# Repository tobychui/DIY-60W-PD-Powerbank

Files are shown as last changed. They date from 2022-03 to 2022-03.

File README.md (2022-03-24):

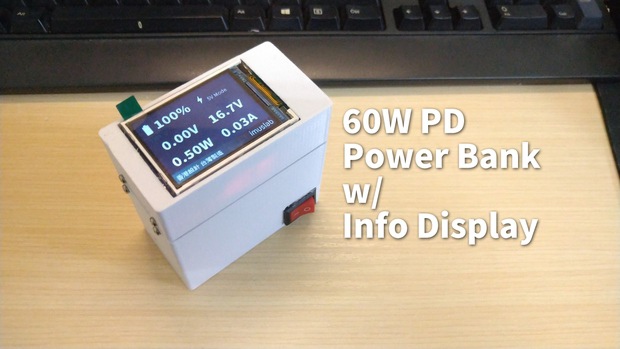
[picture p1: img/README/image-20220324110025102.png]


# DIY-60W-PD-Powerbank

A DIY 60W PD Power bank with real-time battery display for charging your laptop and smartphone

## Introduction

This is a type C only, 20V 3A (60W) supported power bank built by myself. The whole build process is about 2 months and it is a really handy little device to charge your laptop on the go. I designed this so that I don't need to always find a seat with socket nearby during lecture and it really helped me a lot during long and boring lectures :)

## Specification

- Panasonic 14.8V 3200mAh 4S 18650 battery pack
- PD3.0  5 / 9 / 15 / 20V output (Max 20V 3A, 60W)
- Real-time HMI display for battery information (Output power, voltage, battery voltage and drawing current)
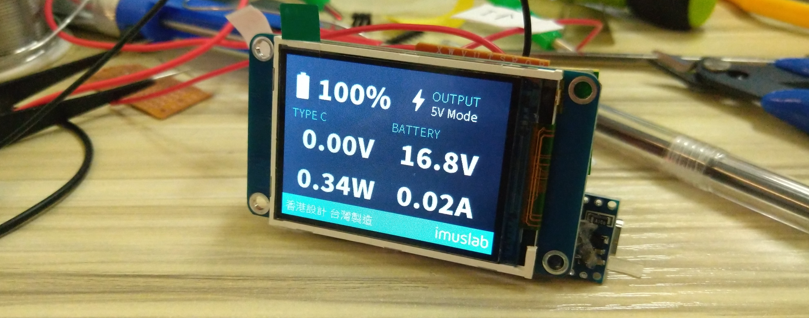
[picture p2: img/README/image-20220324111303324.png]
  

## Building Instructions

This power bank contain 3 main parts. The power bank circuits (the battery, PD management board etc), the Arduino batinfo reader (Arduino, voltage dividers and current sensors) and the HMI display. The overall circuit diagram can be simplified as below.

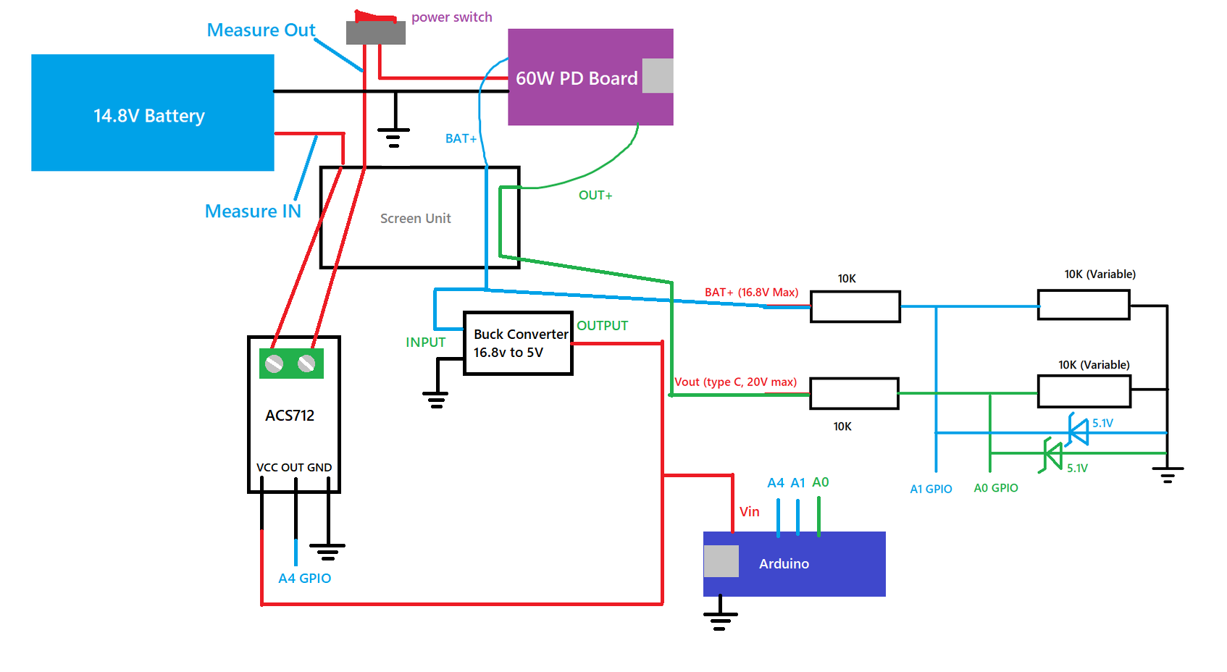
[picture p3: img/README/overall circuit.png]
overall circuit


All the parts then can be glued at the back of the HMI display as follows.

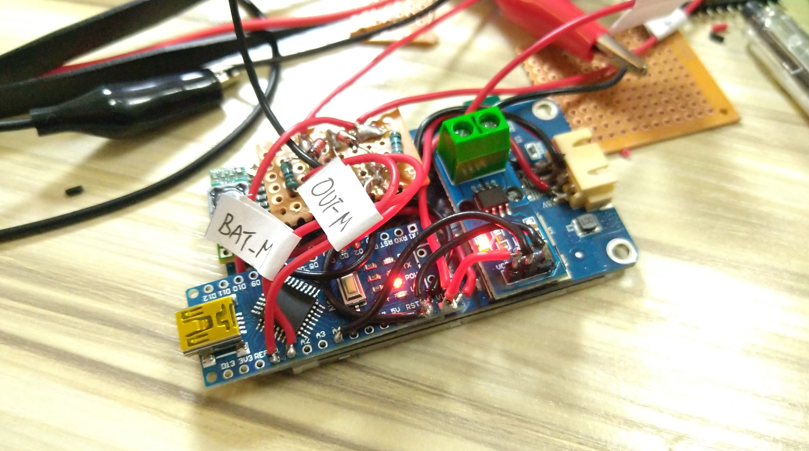
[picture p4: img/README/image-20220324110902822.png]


For more details on the build instructions, see the "Tutorial" folder.

For calibration process for the Arduino measurement sensors, see the Arduino Code folder's README file.

## Case

The case can be printed with a normal FDM printer. See "Case "folder for more information.

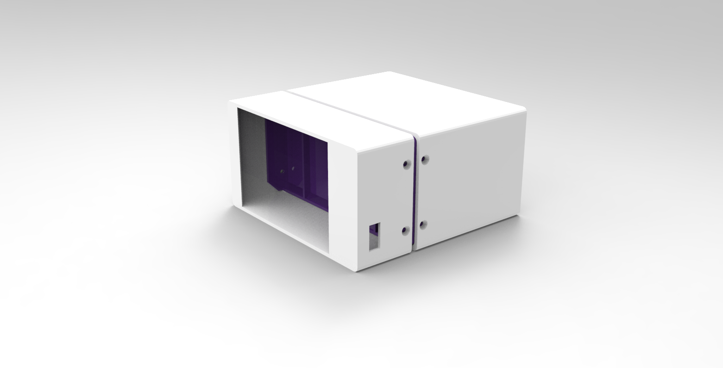
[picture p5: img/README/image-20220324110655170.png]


## Final Product

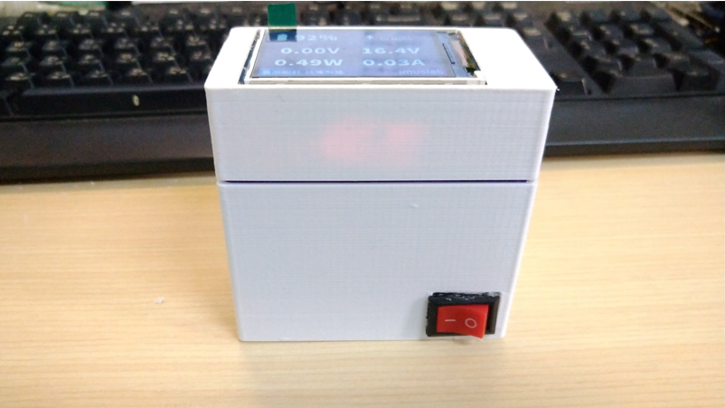
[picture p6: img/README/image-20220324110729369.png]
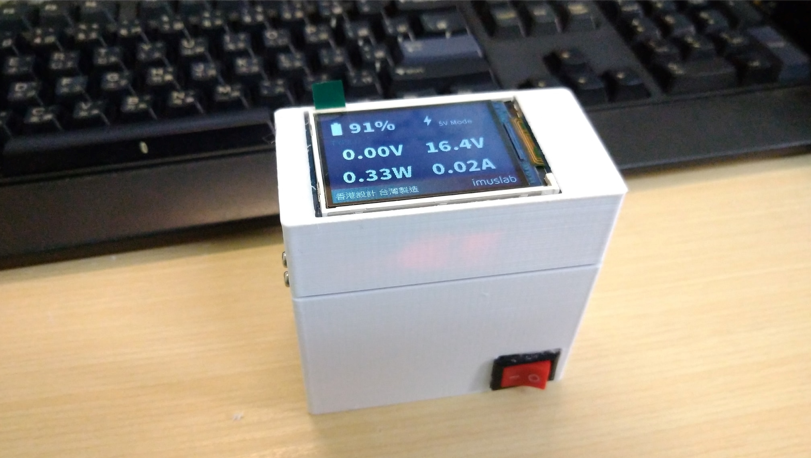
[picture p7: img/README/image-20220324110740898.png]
|  |  |
| --- | --- |
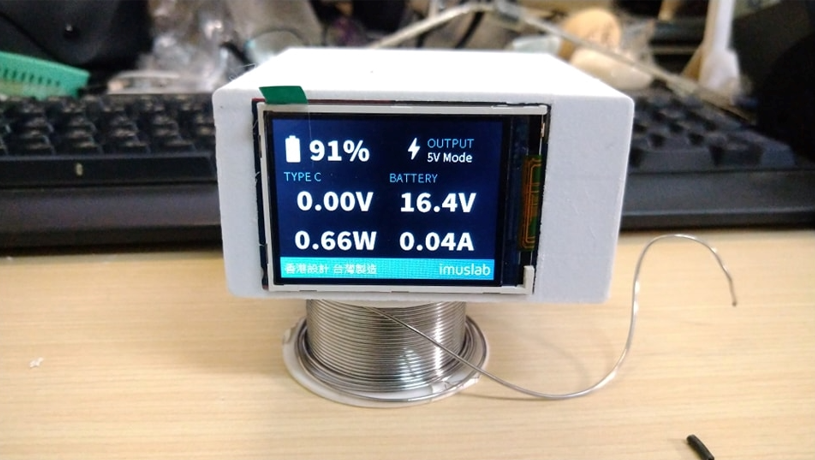
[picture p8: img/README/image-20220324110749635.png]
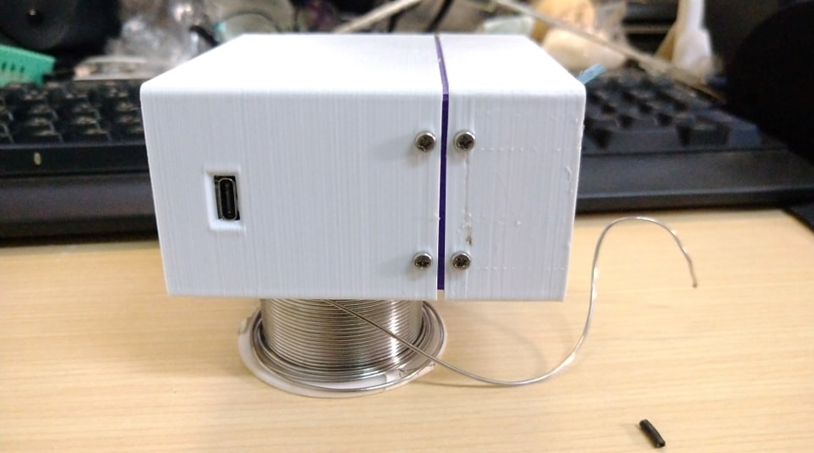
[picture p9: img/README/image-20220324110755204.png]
|  |  |
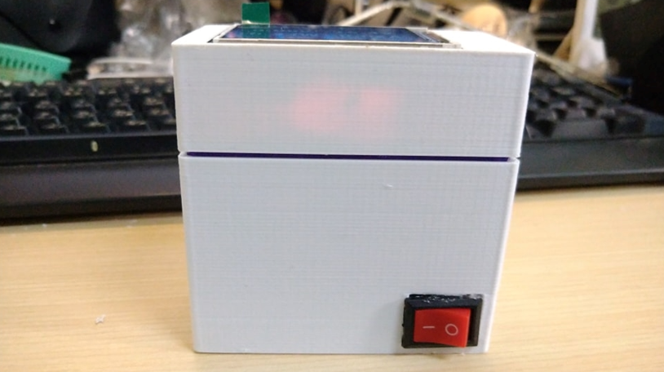
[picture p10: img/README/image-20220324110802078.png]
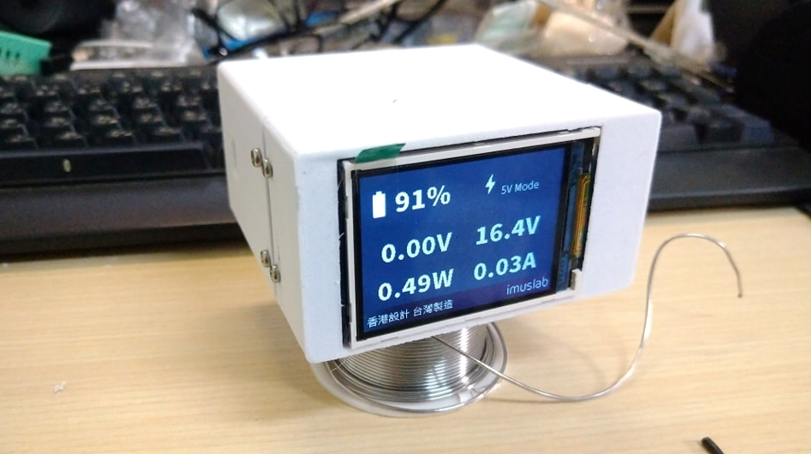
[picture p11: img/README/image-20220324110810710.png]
|  |  |

## License

<br />This work is licensed under a <a rel="license" href="http://creativecommons.org/licenses/by/4.0/">Creative Commons Attribution 4.0 International License</a>.

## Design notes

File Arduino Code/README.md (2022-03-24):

## Battery Monitoring Code for Arduino Nano

This code is design to work with the UARTS HMI display for showing battery real-time information. According to the display design file, the following are the element ids of on screen editable fields. (You can also find it in the code comment section)

```
Loading page
 *  st: Status text

Onscreen elements:
 *  t0: Battery Percentage
 *  t1: Ouput Voltage (5.00V)
 *  t2: Battery Current
 *  t3: OUTPUT / INPUT (OUTPUT)
 *  t4: Voltage Mode (5V Mode)
 *  t5: Power Output (10.0W)
 *  t6: Battery Voltage (14.2V)
 *  t7: label (TYPE C)
 *  t8: label (BATTERY)
 *  
 *  p2: Battery Icon

Battery Icons ID
 *  2 --> 10% left
 *  3 --> 30% left
 *  4 --> 60% left
 *  5 --> 100%
 *  6 --> Charging Icon
```

The following are the pin configurations

```
Type C READ pin = A0
Battery B+ READ pin = A1
Battery Current READ pin = A4

HMI Display Serial Port: D2, D3 (Software Serial RX, TX)
```

As each current reading modules and voltage measurement has offsets and require calibration, you can adjust the current module sensing value in code using the following two variables

```
float currentCalibrationMultiplier = 4.80263; //m
float currentCalibrationOffset = -2.40132; //c
```

Where it follows the ``` y = mx + c``` formula for current estimation.

### Steps to calibrate the current sensor on A4 GPIO

1. Set the battery charging to idle mode. In this mode the current (y) should be 0 and analog read value (x) should be at 2.5v.
2. Plug a 60W charger into the charger connected to a nearly empty battery. In this mode the current (y) should be 3 (i.e. 20V 3A) and the analog read value (x) should be 4 (2.5 + 2.5 * 3/5 = 4 for 5A current measuring module)
3. Solve the two equation two unknown formula
4. Get the value of m and c in y = mx + c as the calibrated offset values

### Steps to calibrate the voltage sensor on A0 and A1 GPIO

Supply the voltage divider with a constant 14.8v and 20v DC with a lab bench power supply. Adjust the variable resistor until the voltage reading on the Arduino Nano match with your power supply.

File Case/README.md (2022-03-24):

## Powerbank Case Design Files

### I only want to print the case

To 3D print the case, you only need the gcode file and a printer with bed size larger than 120 * 120mm. (Compatible with most Marlin firmware based 3D printer)

### I want to customize my case

There are two ways to edit the case to fit your needs. One is using Autodesk Inventor to edit the source files in .ipt formats. 

If you do not have a license to Autodesk Inventor, you can take a look at the "powerbank case.aprint.svg" file and import it to [aPrint Editor](https://aprint.io/editor/) which is a free cloud 3D modeling editor with advance features.

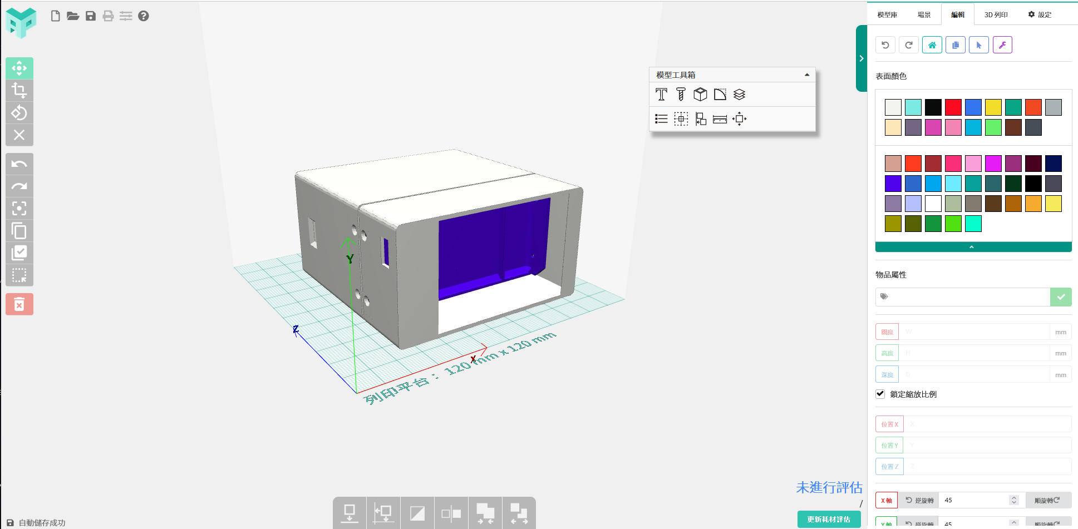
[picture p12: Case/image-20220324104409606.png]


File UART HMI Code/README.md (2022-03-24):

## UARTS HMI Display Code

Should be opened with UARTS HMI Studio

http://wiki.tjc1688.com/doku.php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

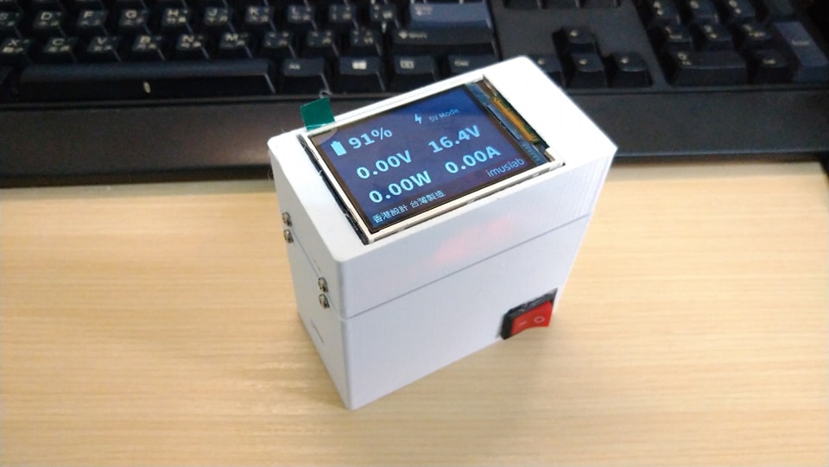
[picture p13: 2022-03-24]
Photo/272983830_10218137504943970_3906996138014400390_n.jpg

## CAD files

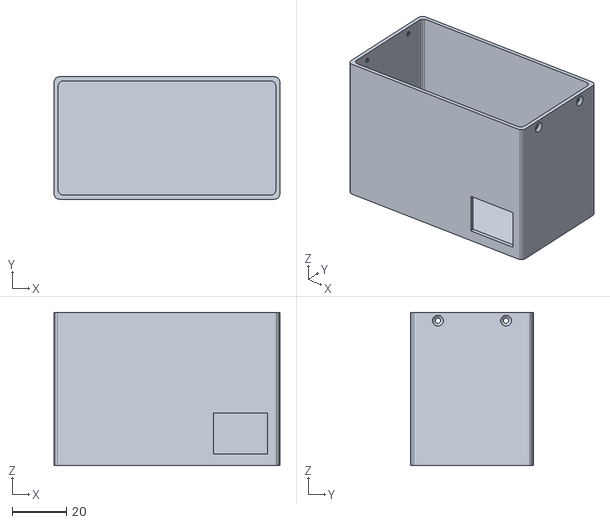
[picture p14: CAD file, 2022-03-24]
Case/stl/battery case.stl
83.0 x 45.0 x 56.2

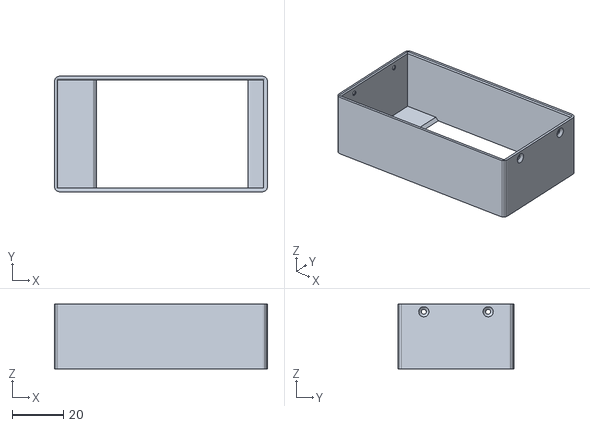
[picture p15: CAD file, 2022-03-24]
Case/stl/screen cover.stl
82.8 x 45.0 x 25.2

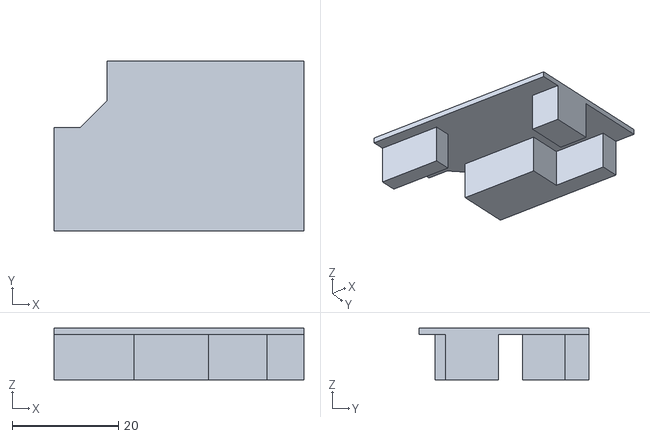
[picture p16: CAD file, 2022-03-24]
Case/stl/PD board supporter.stl
47.0 x 32.0 x 9.70

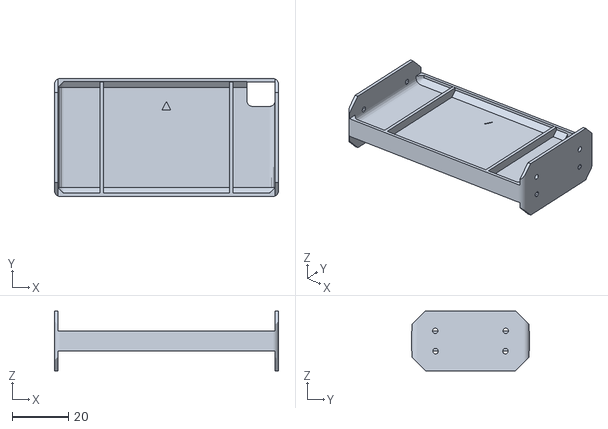
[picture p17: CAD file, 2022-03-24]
Case/stl/screen cover backplate.stl
79.4 x 41.8 x 21.2

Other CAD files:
Case/source/PD board supporter.ipt
Case/source/battery case.ipt
Case/source/screen cover backplate.ipt
Case/source/screen cover.ipt
Case/source/test fit.iam

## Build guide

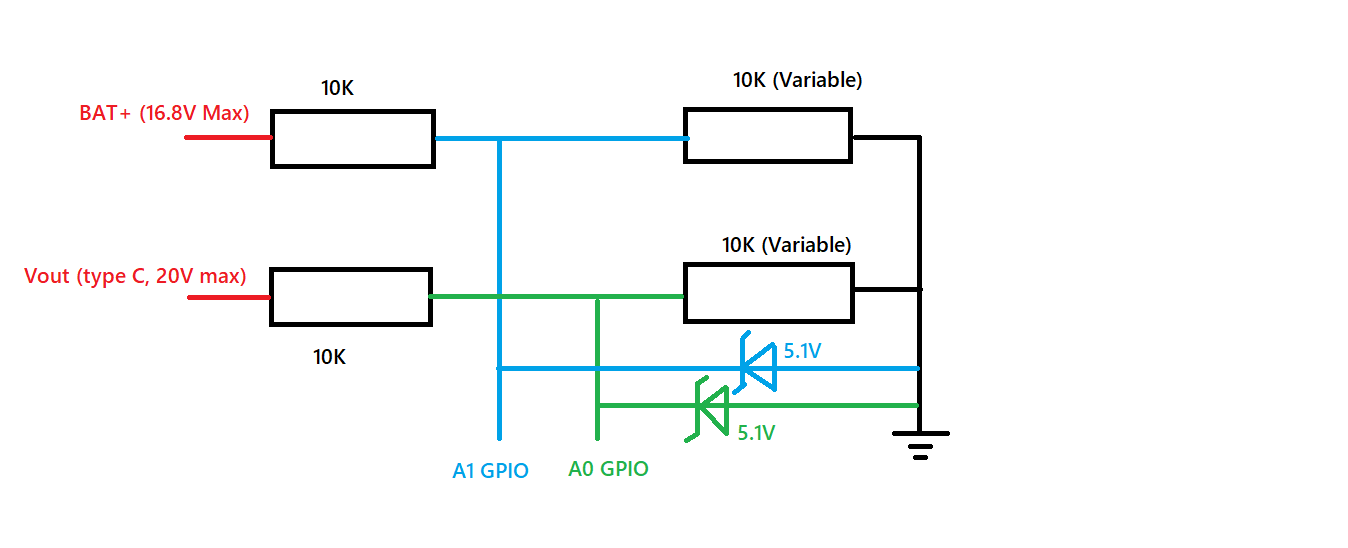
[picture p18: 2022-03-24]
Tutorial/voltage divider.png

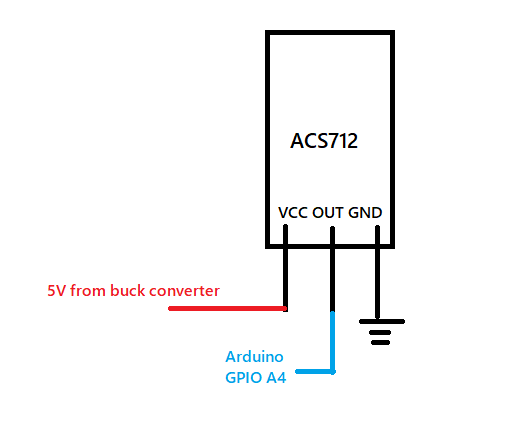
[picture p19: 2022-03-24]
Tutorial/current.png

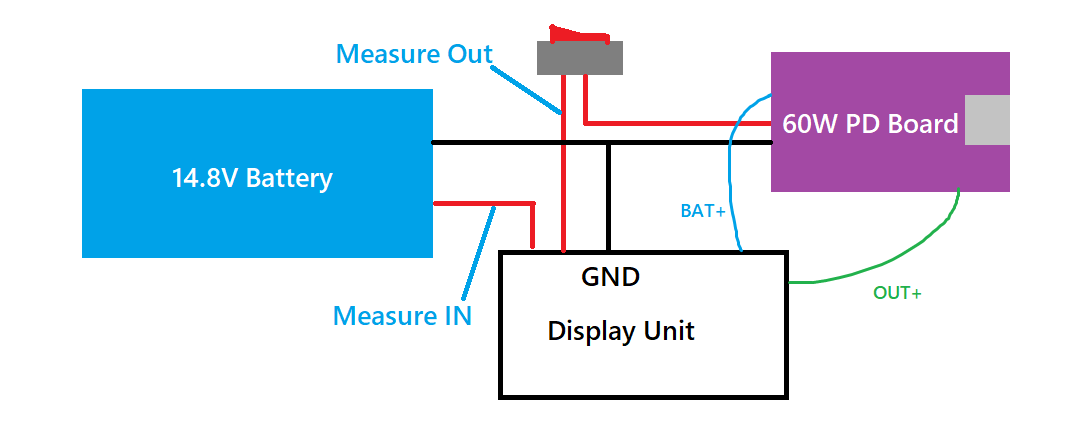
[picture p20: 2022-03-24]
Tutorial/batconn.png

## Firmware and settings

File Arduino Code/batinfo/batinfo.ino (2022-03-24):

/*
 *  imuslab 60W Power Bank Battery Information Display
 *  
 *  Author: tobychui
 *  All Right Reserved
 *  
 *  Loading page
 *  st: Status text
 *  
 *  Onscreen elements:
 *  t0: Battery Percentage
 *  t1: Ouput Voltage (5.00V)
 *  t2: Battery Current
 *  t3: OUTPUT / INPUT (OUTPUT)
 *  t4: Voltage Mode (5V Mode)
 *  t5: Power Output (10.0W)
 *  t6: Battery Voltage (14.2V)
 *  t7: label (TYPE C)
 *  t8: label (BATTERY)
 *  
 *  p2: Battery Icon
 *  Battery Icons ID
 *  2 --> 10% left
 *  3 --> 30% left
 *  4 --> 60% left
 *  5 --> 100%
 *  6 --> Charging Icon
 */ 

#include <SoftwareSerial.h>
const int MAX_READ_LENGTH = 10;
int OUTPUT_READPIN = A0;
int BATTERY_READPIN = A1;
int BATTERY_CURRENT = A4;

//Current calibration values, following y=mx+c where y is correct current and x is the analog read voltage value
float currentCalibrationMultiplier = 4.80263; //m
float currentCalibrationOffset = -2.40132; //c


SoftwareSerial HMISerial(2, 3); // RX, TX
bool debugMode = false;      //Enable debug mode
int currentPageNumber = 0;  //Current Page Number
byte incomingByte = 0;      //Incoming byte buffer
int valbuf = 0; //Analog read value buffer
float BATV, BATA, OUTV, OUTW;

// Send command to the UART HMI
void sendCommand(String cmd){
  if (debugMode){
    //Mirror output to serial
    Serial.print(cmd);
    Serial.write(0XFF);        
    Serial.write(0XFF);
    Serial.write(0XFF);
  }
  HMISerial.print(cmd); 
  HMISerial.write(0XFF);
  HMISerial.write(0XFF);
  HMISerial.write(0XFF);
  delay(100);
}

//Example usage: printFloatCommand("t6.txt=", 16.8, "V");
void printFloatCommand(String cmd, float value, String unit){
  if (debugMode){
    //Mirror output to serial
    Serial.print(cmd + "\"");
    if (value <= -10){
      Serial.print(value, 1);
    }else if (value < 0){
      Serial.print(value, 2);
    }else if (value < 10){
       Serial.print(value, 2);
    }else{
      Serial.print(value, 1);
    }
    Serial.print(unit + "\"");
    Serial.write(0XFF);        
    Serial.write(0XFF);
    Serial.write(0XFF);
  }
  HMISerial.print(cmd + "\"");
  if (value <= -10){
    HMISerial.print(value, 1);
  }else if (value < 0){
    HMISerial.print(value, 2);
  }else if (value < 10){
    HMISerial.print(value, 2);
  }else{
    HMISerial.print(value, 1);
  }
  HMISerial.print(unit + "\"");
  HMISerial.write(0XFF);
  HMISerial.write(0XFF);
  HMISerial.write(0XFF);
  delay(100);
}

float getBatteryVoltage(){
  valbuf = 0;
  for ( int i=0; i < 10; i++){
    valbuf += analogRead(BATTERY_READPIN);
    delay(50);
  }
  return float(valbuf) / 10.0 * 0.016455;
}

float getOutputVoltage(){
  valbuf = 0;
  for ( int i=0; i < 10; i++){
    valbuf += analogRead(OUTPUT_READPIN);
    delay(50);
  }
  return float(valbuf) / 10.0 * 0.019537;
}


float getBatteryCurrent(){
  valbuf = analogRead(BATTERY_CURRENT);
  int current = (valbuf / 1024.0 * 500) - 250;
  return (float(current) / 100) * currentCalibrationMultiplier + currentCalibrationOffset; 
}

float getTotalOutputPower(float batV, float batA){
  return batV * batA;
}

int estimateBatteryPercentage(float batV){
  valbuf = 0.0;
  //Cap the max voltage for rendering
  if (batV > 16.8){
    batV = 16.8;
  }else if (batV < 13.09){
    batV = 13.09;
  }

  int batmV = int(batV * 100);

  //Reconstruct the battery capacity curve
  if (batmV > 1660){
    //Near 100% parts
    valbuf = 100;
  }else if (batmV > 1550){
    //60 - 100
    valbuf = map(batmV, 1550, 1660, 60, 100);
  }else if (batmV > 1518){
    //40 - 60
    valbuf = map(batmV, 1518, 1550, 40, 60);
  }else if (batmV > 1483){
    //10 - 40
    valbuf = map(batmV, 1483, 1518, 10, 40);
  }else{
    //Under 10%
    valbuf = map(batmV, 1309, 1483, 1, 10);
  }
  
  return int(valbuf);
}

//Change the battery icon according to charge status
void updateBatteryIcon(int batPercentage, bool isCharging){
  if (isCharging){
    //Charging
    sendCommand("p2.pic=6");
  }else{
    //Discharging
    if (batPercentage >= 80){
      sendCommand("p2.pic=5");
    }else if (batPercentage >= 60){
        sendCommand("p2.pic=4");
    }else if (batPercentage >= 30){
      sendCommand("p2.pic=3");
    }else{
      sendCommand("p2.pic=2");
    }
  }
}


int getPageNumber(){
  //Request the UART HMI to return its current page number
  sendCommand("sendme");

  //Try to parse and catch the return value
  bool nextReadIsPageNumber = false;
  if (debugMode){
    //Debug mode
    while (Serial.available() > 0) {
      // read the incoming byte:
      incomingByte = Serial.read();
      if (nextReadIsPageNumber){
        //This read is the page number
        nextReadIsPageNumber = false;
        return incomingByte;
      }

      if (incomingByte == 0x66){
        //This is the start of a page response
        nextReadIsPageNumber = true;
      }
    }
  }else{
    while (HMISerial.available() > 0) {
      // read the incoming byte:
      incomingByte = HMISerial.read();
      if (nextReadIsPageNumber){
        //This read is the page number
        nextReadIsPageNumber = false;
        return incomingByte;
      }

      if (incomingByte == 0x66){
        //This is the start of a page response
        nextReadIsPageNumber = true;
      }
    }
  }

  return -1;
}

// initization of display if the screen is resetted
void initDisplayIfPage0(){
  //Check if the current page is page 0
  currentPageNumber = getPageNumber();
  if (currentPageNumber == 0x00){
    //Page 0, run init check
    digitalWrite(LED_BUILTIN, HIGH);
    
    sendCommand("st.txt=\"MCU Connected (OK)\"");
    delay(500);
    sendCommand("st.txt=\"System Check (OK)\"");
    //Do checking here
    delay(200);
    printFloatCommand("st.txt=",getBatteryCurrent()," ACS712 (OK)");  
    delay(200);
    valbuf = getBatteryVoltage();
    if (valbuf > 10){
      printFloatCommand("st.txt=",valbuf," BATV (OK)");  
      delay(200);
      printFloatCommand("st.txt=",float(estimateBatteryPercentage(valbuf))," BAT% (OK)");
    }else{
      printFloatCommand("st.txt=",valbuf," BATV (FAILED)");
      delay(5000);
    }
    delay(200);
    printFloatCommand("st.txt=",getOutputVoltage()," OUTV (OK)");
    //Finally, switch to info page
    delay(1000);
    sendCommand("page 1");
  }else{
    //Other pages
    digitalWrite(LED_BUILTIN, LOW);
  }
}

//Main logic for getting and updating the battery logic
void updateBatteryInformation(){
  //Get basic information
  OUTV = getOutputVoltage();
  BATV = getBatteryVoltage();
  BATA = getBatteryCurrent();
  OUTW = getTotalOutputPower(BATV, BATA);
  printFloatCommand("t1.txt=", OUTV, "V");
  printFloatCommand("t6.txt=", BATV, "V");
  printFloatCommand("t5.txt=", OUTW, "W");
  printFloatCommand("t2.txt=", BATA, "A");

  //Get Battery Capacity
  sendCommand("t0.txt=\"" + String(estimateBatteryPercentage(BATV))+ "%\"");
  
  //Estimate the output mode
  if (OUTV < 7.0){
    //5V Mode
    sendCommand("t4.txt=\"5V Mode\"");
  }else if (OUTV < 10.0){
    //9V Mode
    sendCommand("t4.txt=\"9V Mode\"");
  }else if (OUTV < 13.0){
    //12V Mode
    sendCommand("t4.txt=\"12V Mode\"");
  }else if (OUTV < 17.0){
    //15V Mode
    sendCommand("t4.txt=\"15V Mode\"");
  }else{
    //20V Mode
    sendCommand("t4.txt=\"20V Mode\"");
  }

  if (BATA < -0.1){
    sendCommand("t3.txt=\"INPUT\"");
    sendCommand("t3.pco=61440");
    updateBatteryIcon(estimateBatteryPercentage(BATV), true);
  }else{
    sendCommand("t3.txt=\"OUTPUT\"");
    sendCommand("t3.pco=11928");
    updateBatteryIcon(estimateBatteryPercentage(BATV), false);
  }
}

// the setup function runs once when you press reset or power the board
void setup() {
  //Setup the serial and software serial
  Serial.begin(115200);
  HMISerial.begin(9600);

  //Setup debug LED
  pinMode(LED_BUILTIN, OUTPUT);

  /*
  pinMode(A3, OUTPUT);
  pinMode(A5, OUTPUT);
  digitalWrite(A3, HIGH);
  digitalWrite(A5, LOW);
  */
  }

// the loop function runs over and over again forever
void loop() {
  initDisplayIfPage0();
  updateBatteryInformation();
}
